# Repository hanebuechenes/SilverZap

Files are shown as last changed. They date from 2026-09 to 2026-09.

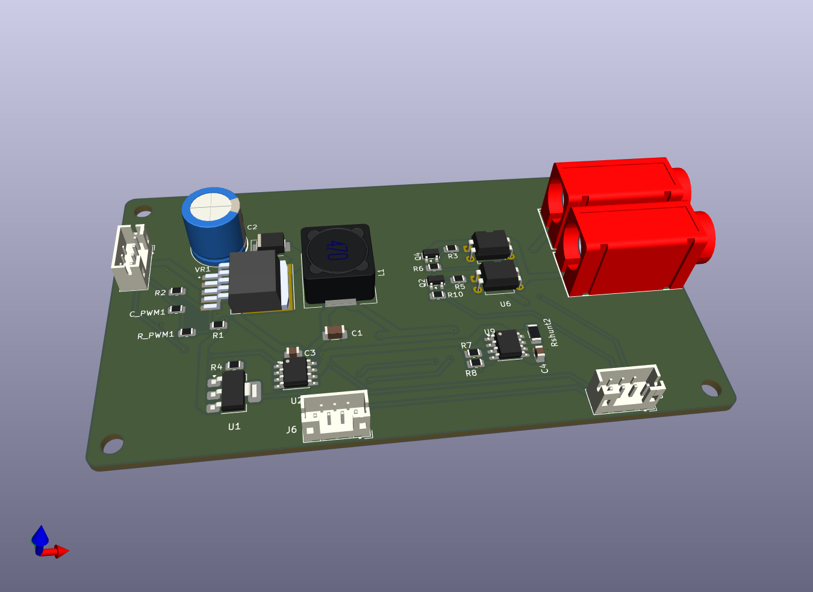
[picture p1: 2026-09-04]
hardware/KiCad/SilverZap_PCB_01.png

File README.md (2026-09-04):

## 📜 Lizenzierung / License

Dieses Projekt ist unter dualen Open-Source-Lizenzen veröffentlicht:

* **Hardware & Design (KiCad, Gerber, 3D-STL/STEP):**  
  Lizenziert unter [Creative Commons Attribution 4.0 International (CC BY 4.0)](LICENSE-HARDWARE.txt).  
  

* **Software & Firmware (C++ Source Code):**  
  Lizenziert unter der [GNU General Public License v3.0 (GPLv3)](LICENSE).  


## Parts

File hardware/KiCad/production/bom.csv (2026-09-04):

Designator | Footprint | Quantity | Value | LCSC Part #
C1 | 1206 | 1 | 100uF/16V
C2 | CP_Radial_D10.0mm_P5.00mm | 1 | 220uF/63V
C3, C4 | 0805 | 2 | 100nF
CN1, CN2 | CONN-TH_24.243.1_RED | 2 | 24.243.1 | C7437321
C_PWM1 | 0805 | 1 | 100nF 50V
D1 | D_SMB | 1 | SS36
J3, J5, J6 | JST_PH_B4B-PH-K_1x04_P2.00mm_Vertical | 3 | Conn_01x04
L1 | L_12x12mm_H6mm | 1 | 33uH
Q2, Q4 | SOT-23 | 2 | 2N7002
R1 | 0805 | 1 | 470k 1%
R10, R6 | 0805 | 2 | 10k
R2 | 0805 | 1 | 10k 1%
R3, R5 | 0805 | 2 | 330R
R4 | 0805 | 1 | 1,25k
R7, R8 | 0805 | 2 | 4,7k
RSHUNT2 | 1206 | 1 | 0,1R 1%
R_PWM1 | 0805 | 1 | 100k 1%
U1 | SOT-223-3_TabPin2 | 1 | LM317_SOT-223
U2 | SOIC-8_3.9x4.9mm_P1.27mm | 1 | MCP41010
U5, U6 | DIP-4_W7.62mm | 2 | EL817
U9 | SOIC-8_3.9x4.9mm_P1.27mm | 1 | INA219AxD
VR1 | DPAK170P1435X465-6N | 1 | XL6009

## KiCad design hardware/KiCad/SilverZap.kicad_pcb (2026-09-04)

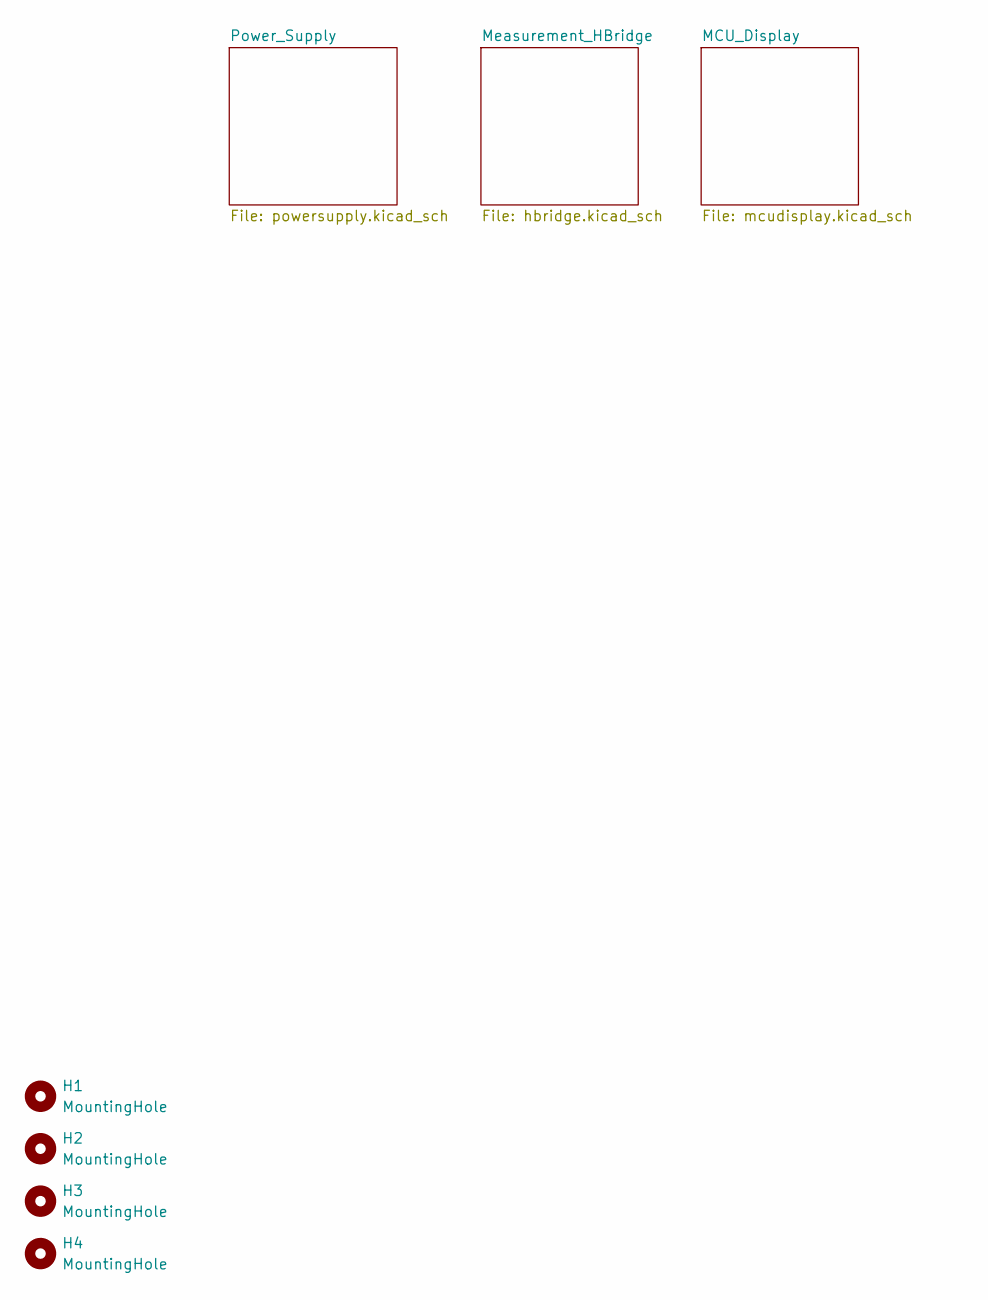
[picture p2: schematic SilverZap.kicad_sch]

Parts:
H1, H2, H3, H4: MountingHole; MountingHole_3.2mm_M3

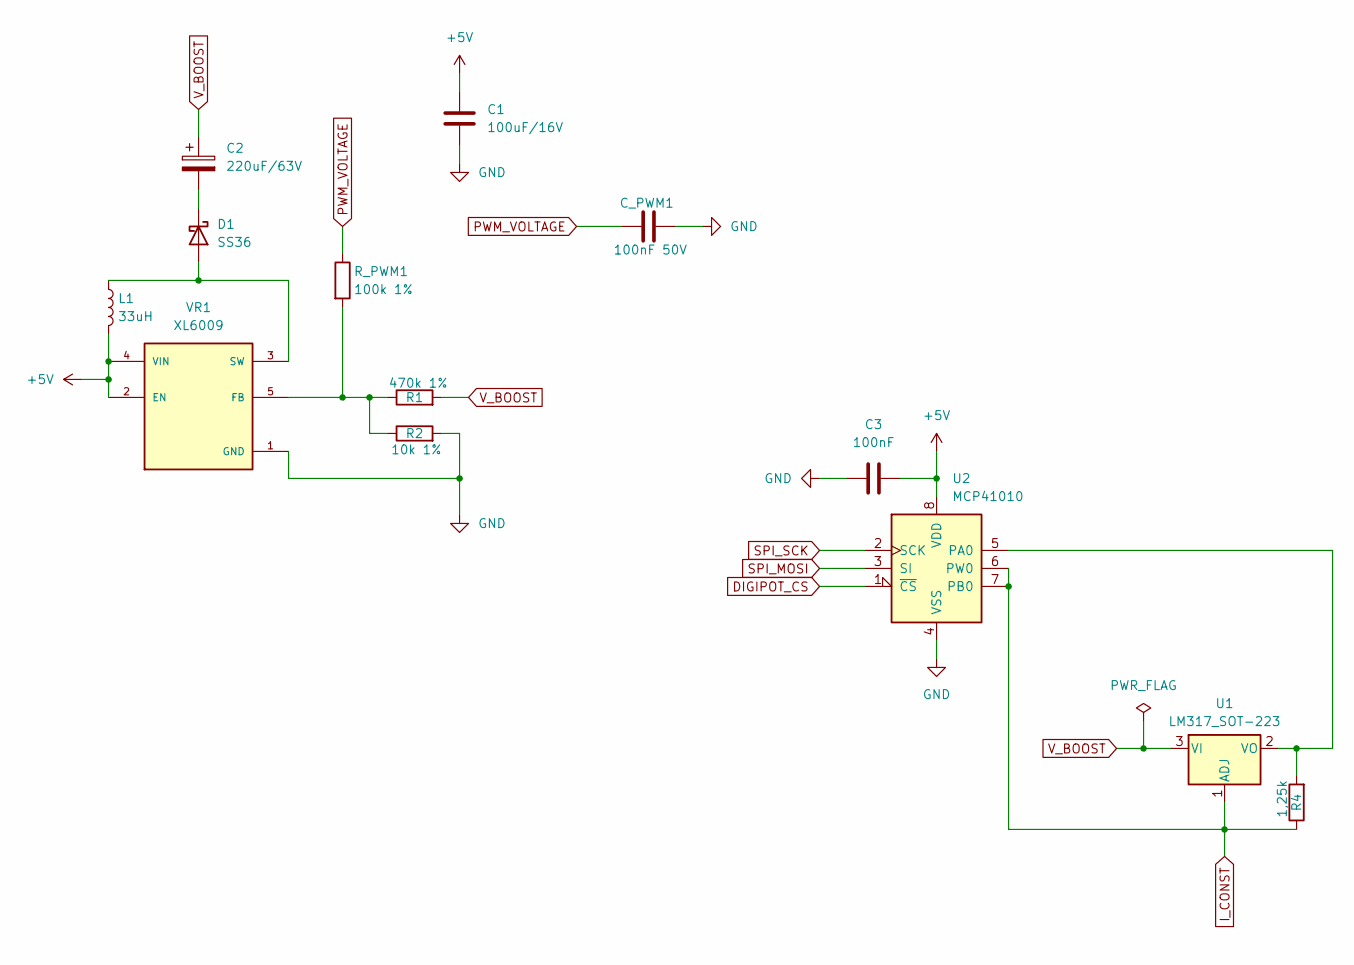
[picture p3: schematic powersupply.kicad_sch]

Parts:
C1: 100uF/16V; C_1206_3216Metric
C2: 220uF/63V; CP_Radial_D10.0mm_P5.00mm
C3: 100nF; C_0805_2012Metric
C_PWM1: 100nF 50V; R_0805_2012Metric
D1: SS36; D_SMB
L1: 33uH; L_12x12mm_H6mm
R1: 470k 1%; R_0805_2012Metric
R2: 10k 1%; R_0805_2012Metric
R4: 1,25k; R_0805_2012Metric
R_PWM1: 100k 1%; R_0805_2012Metric
U1: LM317_SOT-223; SOT-223-3_TabPin2
U2: MCP41010; SOIC-8_3.9x4.9mm_P1.27mm
VR1: XL6009; DPAK170P1435X465-6N; PARTREV 1.1

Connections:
+5V: C1.1, C3.2, L1.2, U2.8 (VDD), VR1.2 (EN), VR1.4 (VIN); also elsewhere on the board
DIGIPOT_CS: U2.1 (~CS); also elsewhere on the board
GND: C1.2, C3.1, C_PWM1.2, R2.2, U2.4 (VSS), VR1.1 (GND); also elsewhere on the board
I_CONST: R4.1, U1.1 (ADJ), U2.6 (PW0), U2.7 (PB0); also elsewhere on the board
unnamed: D1.2 (A), L1.1, VR1.3 (SW), VR1.6 (SW)
unnamed: C2.2, D1.1 (K)
unnamed: R4.2, U1.2 (VO), U2.5 (PA0)
unnamed: R1.1, R2.1, R_PWM1.2, VR1.5 (FB)
PWM_VOLTAGE: C_PWM1.1, R_PWM1.1; also elsewhere on the board
SPI_MOSI: U2.3 (SI); also elsewhere on the board
SPI_SCK: U2.2 (SCK); also elsewhere on the board
V_BOOST: C2.1, R1.2, U1.3 (VI)

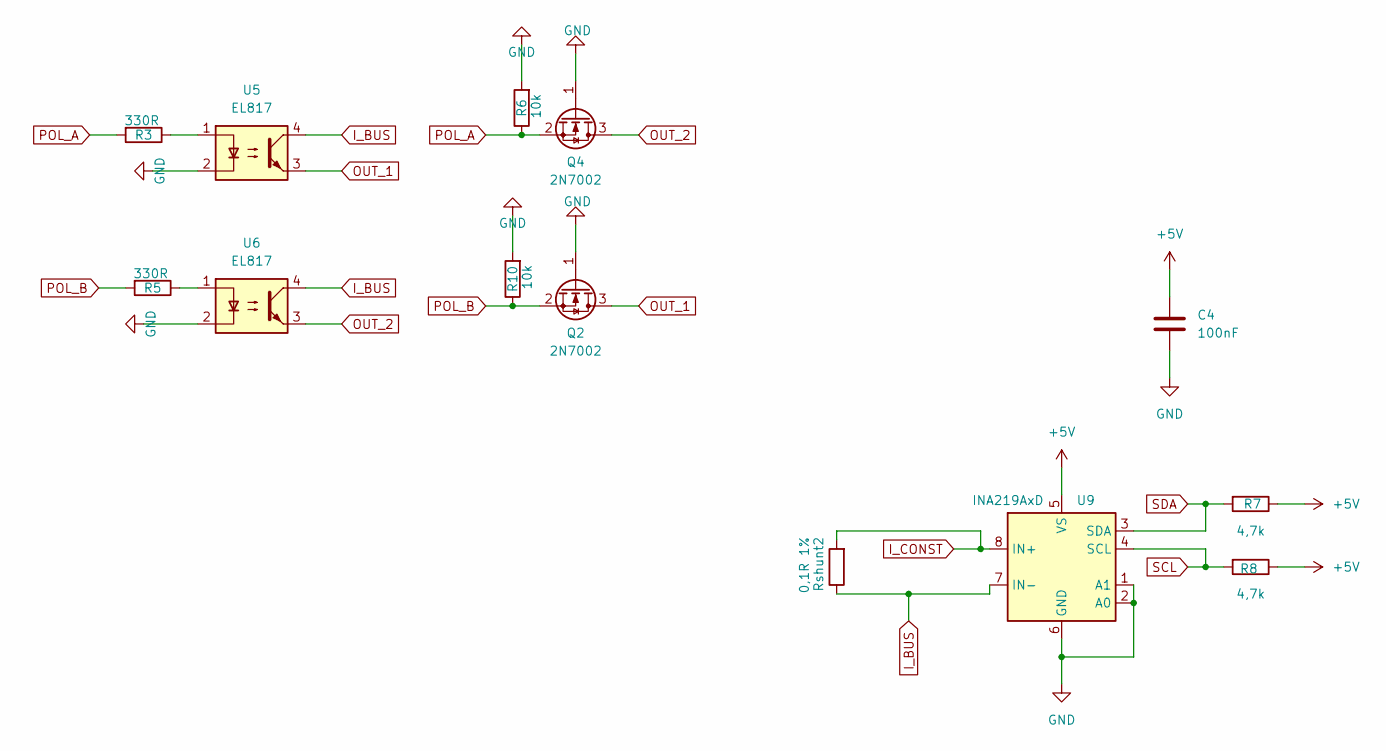
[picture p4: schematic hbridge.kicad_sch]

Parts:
C4: 100nF; C_0805_2012Metric
Q2, Q4: 2N7002; SOT-23
R3, R5: 330R; R_0805_2012Metric
R6, R10: 10k; R_0805_2012Metric
R7, R8: 4,7k; R_0805_2012Metric
Rshunt2: 0,1R 1%; R_1206_3216Metric
U5, U6: EL817; DIP-4_W7.62mm
U9: INA219AxD; SOIC-8_3.9x4.9mm_P1.27mm

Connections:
+5V: C4.1, R7.1, R8.1, U9.5 (VS); also elsewhere on the board
GND: C4.2, Q2.1 (G), Q4.1 (G), R6.2, R10.2, U5.2, U6.2, U9.1 (A1), U9.2 (A0), U9.6 (GND); also elsewhere on the board
I_BUS: Rshunt2.1, U5.4, U6.4, U9.7 (IN-)
I_CONST: Rshunt2.2, U9.8 (IN+); also elsewhere on the board
unnamed: R3.1, U5.1
unnamed: R5.1, U6.1
OUT_1: Q2.3 (D), U5.3; also elsewhere on the board
OUT_2: Q4.3 (D), U6.3; also elsewhere on the board
POL_A: Q4.2 (S), R3.2, R6.1; also elsewhere on the board
POL_B: Q2.2 (S), R5.2, R10.1; also elsewhere on the board
SCL: R8.2, U9.4 (SCL); also elsewhere on the board
SDA: R7.2, U9.3 (SDA); also elsewhere on the board

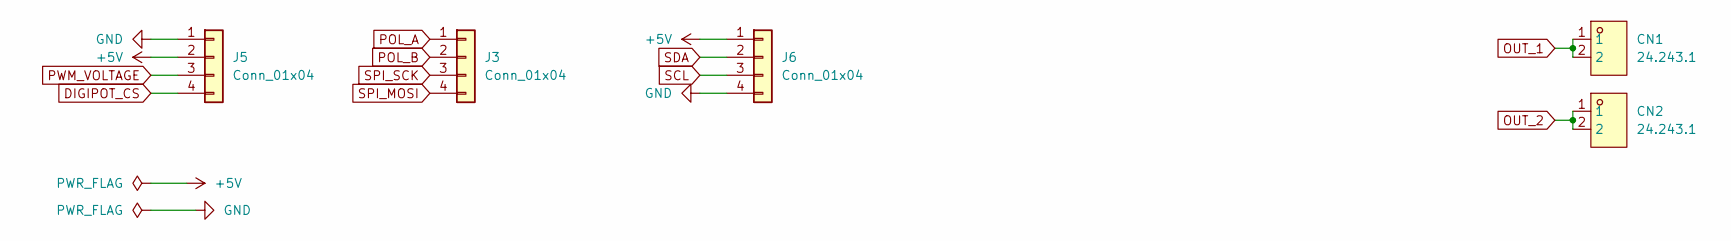
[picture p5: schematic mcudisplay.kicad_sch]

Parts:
CN1, CN2: 24.243.1; CONN-TH_24.243.1_RED; MPN 24.243.1; LCSC Part C7437321
J3, J5, J6: Conn_01x04; JST_PH_B4B-PH-K_1x04_P2.00mm_Vertical

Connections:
+5V: J5.2, J6.1; also elsewhere on the board
DIGIPOT_CS: J5.4; also elsewhere on the board
GND: J5.1, J6.4; also elsewhere on the board
OUT_1: CN1.1, CN1.2; also elsewhere on the board
OUT_2: CN2.1, CN2.2; also elsewhere on the board
POL_A: J3.1; also elsewhere on the board
POL_B: J3.2; also elsewhere on the board
PWM_VOLTAGE: J5.3; also elsewhere on the board
SCL: J6.3; also elsewhere on the board
SDA: J6.2; also elsewhere on the board
SPI_MOSI: J3.4; also elsewhere on the board
SPI_SCK: J3.3; also elsewhere on the board

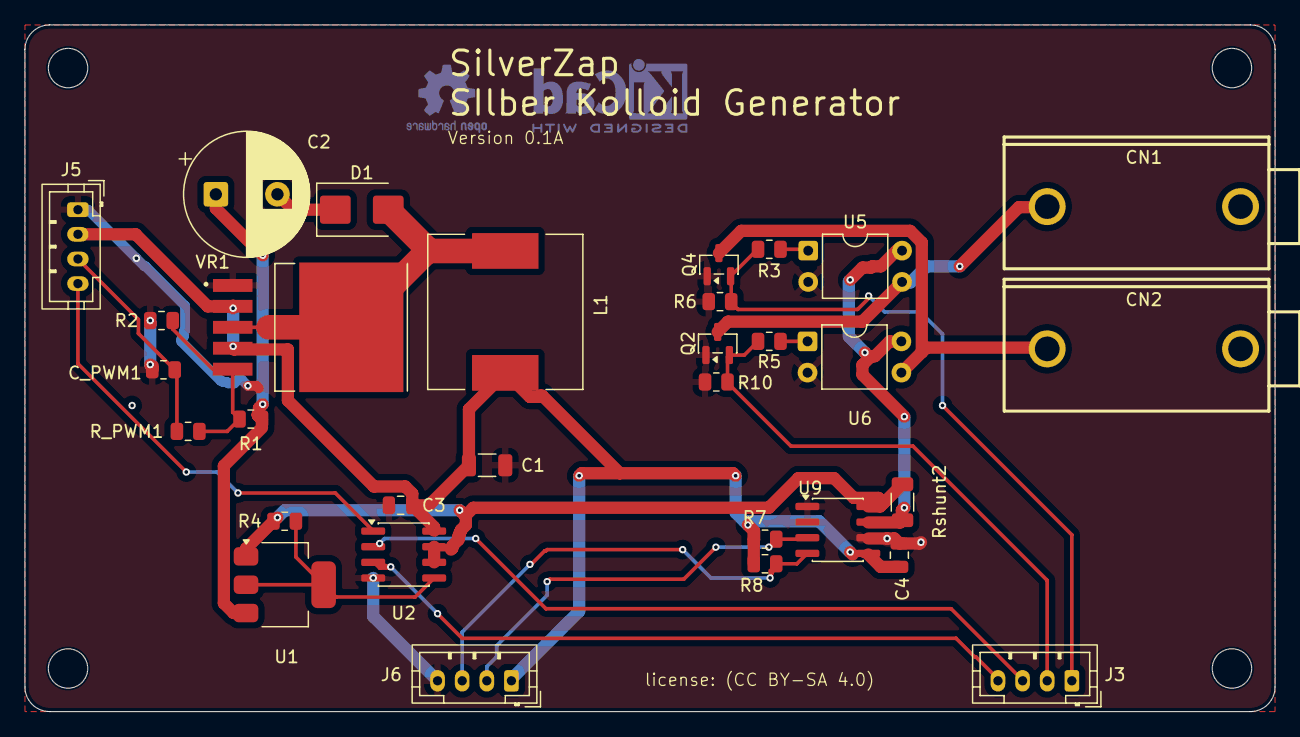
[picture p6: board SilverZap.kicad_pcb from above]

Board: 2 copper layers, 101.5 x 55.8 mm, 35 parts (0 on the bottom side), 21 nets.

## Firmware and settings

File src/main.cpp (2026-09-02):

#include <Arduino.h>

// put function declarations here:
int myFunction(int, int);

void setup() {
  // put your setup code here, to run once:
  int result = myFunction(2, 3);
}

void loop() {
  // put your main code here, to run repeatedly:
}

// put function definitions here:
int myFunction(int x, int y) {
  return x + y;
}

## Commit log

2026-09-04 Lokale Dateien und 3D-Objekte hinzugefügt
    [IO.kicad_sch, SilverZap.kicad_pcb, SilverZap.kicad_sch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]
2026-09-04 Entferne .vscode und temporäre Dateien aus dem Repo

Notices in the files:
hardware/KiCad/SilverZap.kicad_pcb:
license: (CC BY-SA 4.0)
